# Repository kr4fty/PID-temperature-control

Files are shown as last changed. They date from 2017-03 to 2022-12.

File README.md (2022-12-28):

# PID-temperature-control

Temperature control of an oven/heater made with Arduino Uno (atmega328p microcontroller).
For it, a PID controller is used which will provide a constant temperature at the outlet, according to that established by the user.

This is an implementation of the ovenControl library for Arduino boards.

## Description:
The system maintains a constant temperature at which it is selected. It can vary between 0 and 420ºC.

## Software
These are the libraries required for their operation:

* Lcd: [Adafruit-PCD8544-Nokia-5110-LCD-library](https://github.com/adafruit/Adafruit-PCD8544-Nokia-5110-LCD-library).
* Keyboard: [AnalogKeypad](https://github.com/kr4fty/AnalogKeyPad).
* Menu: [MenuPCD8544](https://github.com/kr4fty/MenuPCD8544).
* K thermocouple: [K-Type_thermocouple-Library](https://github.com/kr4fty/K-Type_thermocouple-Library).
* OvenControl: [ovenControl](https://github.com/kr4fty/ovenControl).

## Hardware:
The system is composed of five main parts

* **The microcontroller**: brain in charge of the administration of resources.
* **Display and keyboard**: is the user interface. It uses a lcd of a Nokia 3310/5510 and a ladder type keyboard.
* **The temperature sensor**: in charge of constantly measuring the temperature of the oven/heater and in this way can make the feedback towards the control for the respective adjustments. For this function a K-type thermocouple  is used.
* **AC control**: in charge of handling AC, in this case I will use 220Vac/50Hz. For this purpose opto-thyristors are used, which act as a solid state relay.
* **Zero crossing detector**: in charge of activating the thyristors from the moment in which the alternating voltage wave is detected crosses by zero.For this function a K-type thermocouple is used.

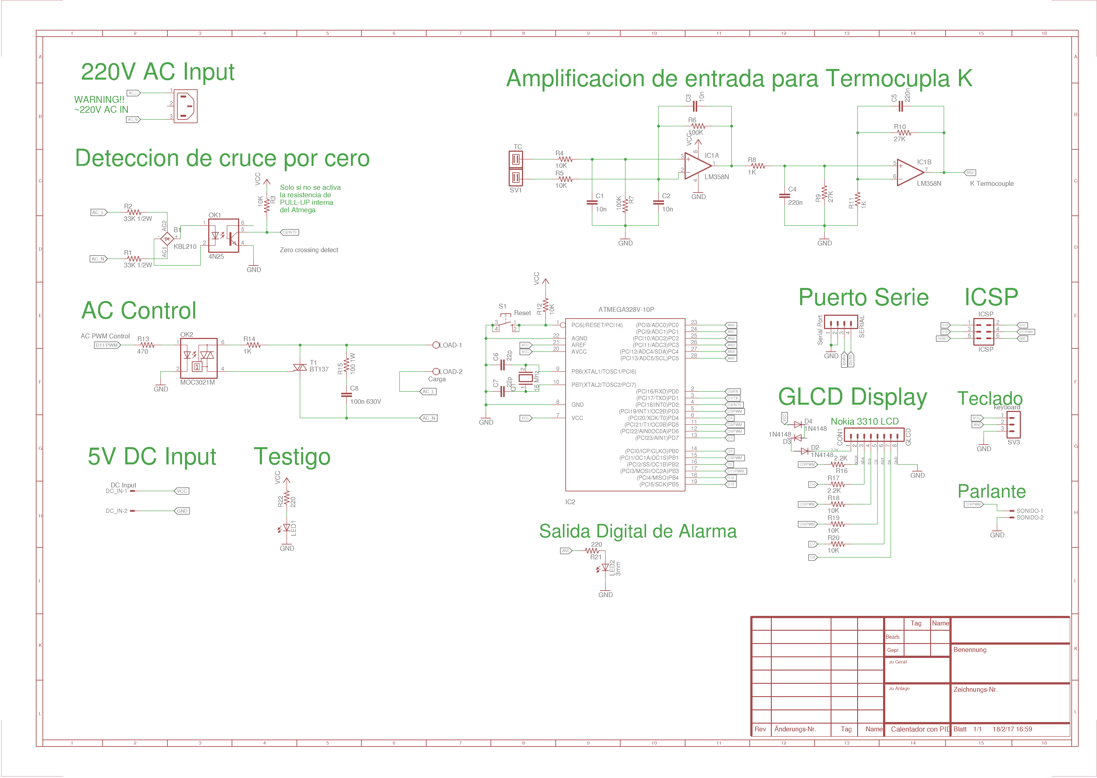
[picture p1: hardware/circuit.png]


## Video
Oven Control (https://www.youtube.com/watch?v=Dz5Lqh4SREI "PID Oven Control")

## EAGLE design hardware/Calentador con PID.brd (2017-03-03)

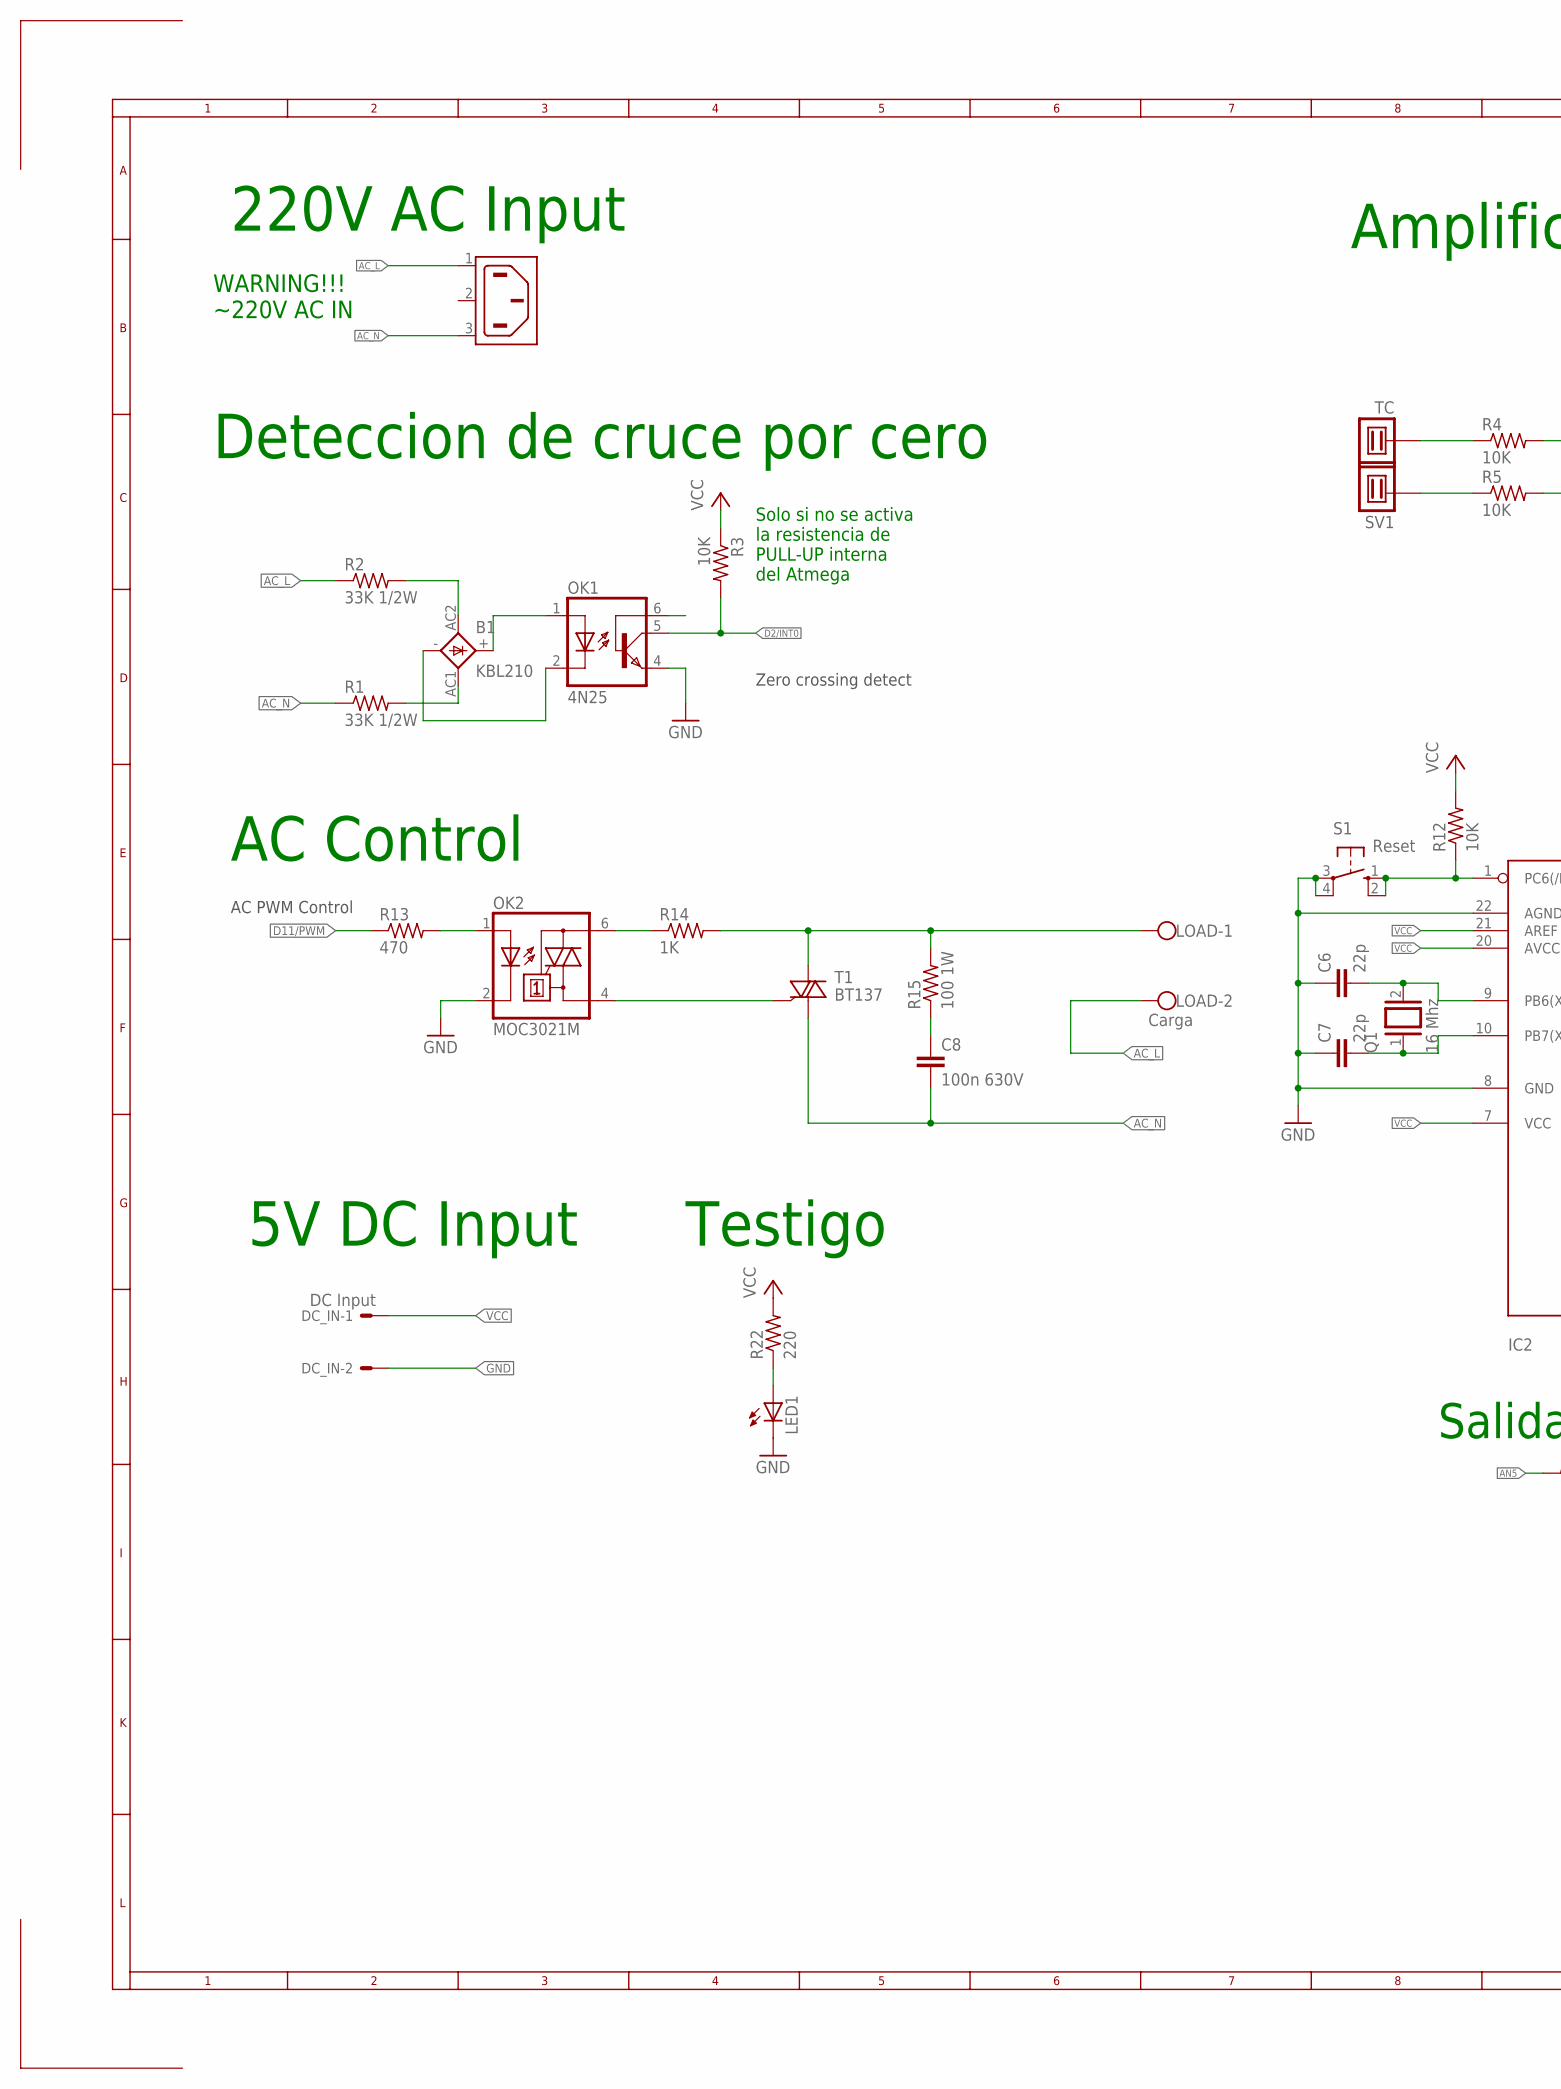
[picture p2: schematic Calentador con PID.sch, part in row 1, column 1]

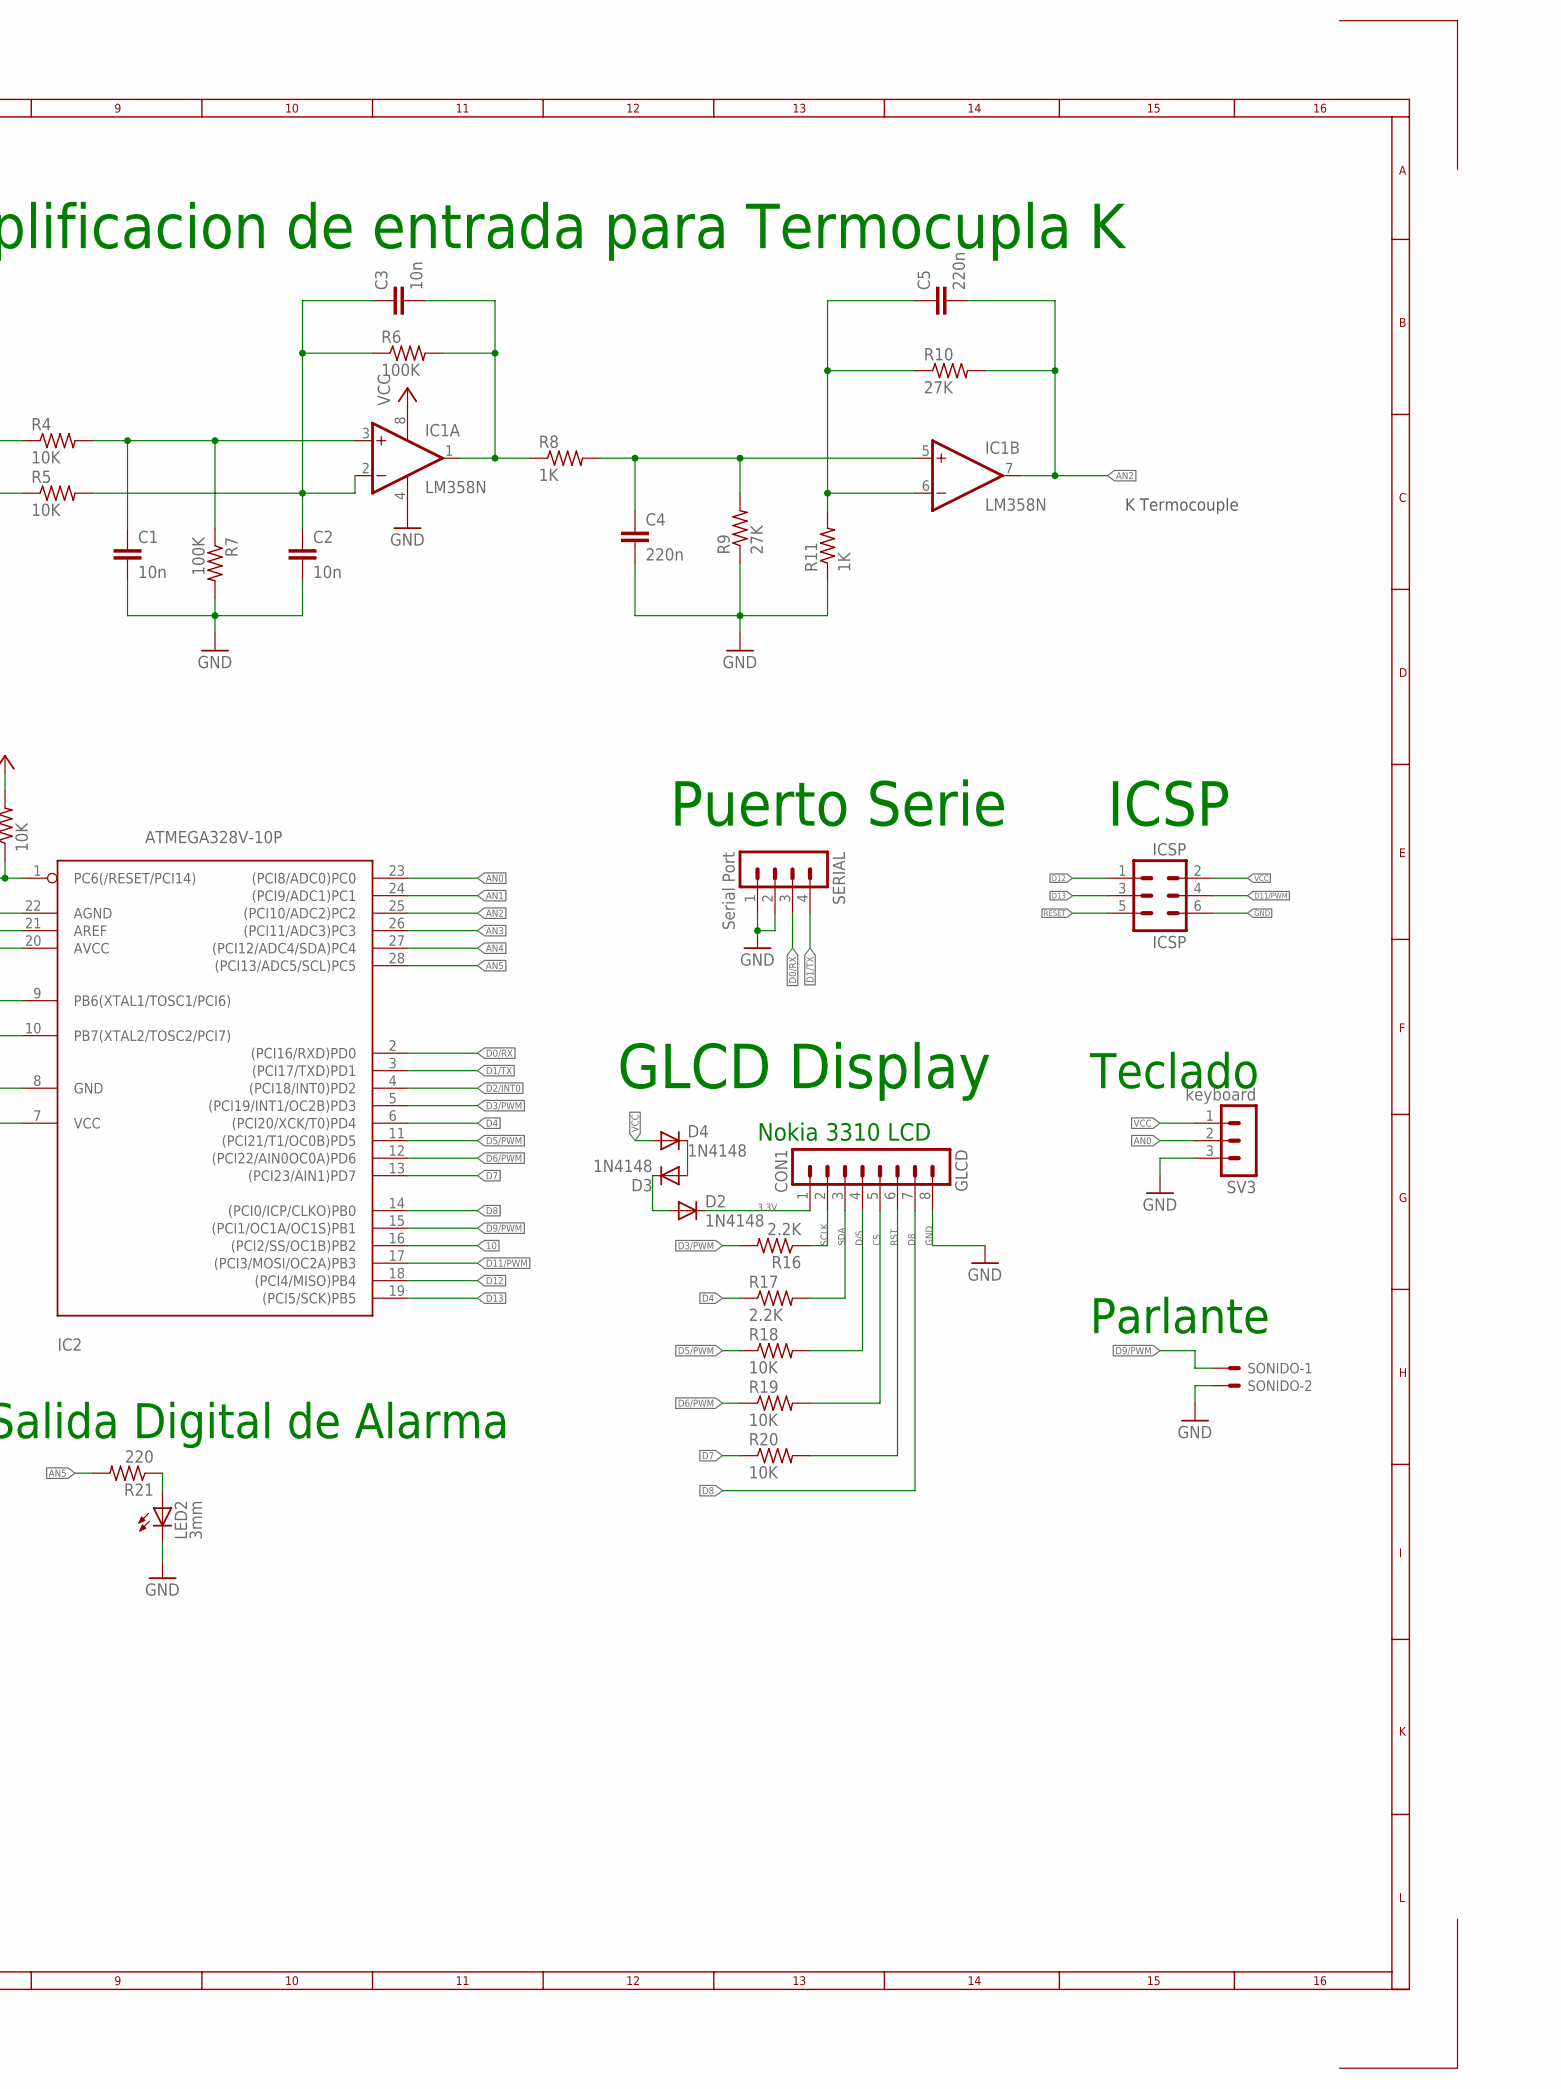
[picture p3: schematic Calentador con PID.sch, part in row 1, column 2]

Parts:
B1: KBL210; KBL
C1, C2, C3: 10n; C050-024X044
C4, C5: 220n; C050-025X075
C6, C7: 22p; C050-025X075
C8: 100n 630V; C102-043X133
D2, D3, D4: 1N4148; DO35-7
DC_IN: DC Input; 22-23-2021
GLCD: CON1; MA08-1
IC1: LM358N; DIL08
IC2: ATMEGA328V-10P; DIL28-3
ICSP: ICSP; MA03-2
LED1: LED3MM
LED2: 3mm; Q62902-B155
LOAD: Carga; W237-102
OK1: 4N25; DIL06
OK2: MOC3021M; DIL06
Q1: 16 Mhz; QS
R1, R2: 33K 1/2W; 0207/2V
R3, R4, R5, R18, R19, R20: 10K; 0207/7
R6: 100K; 0207/2V
R7: 100K; 0207/7
R8, R14: 1K; 0207/2V
R9: 27K; 0207/7
R10: 27K; 0207/2V
R11: 1K; 0207/7
R12: 10K; 0207/15
R13: 470; 0207/10
R15: 100 1W; 0207/2V
R16, R17: 2.2K; 0207/10
R21: 220; 0207/7
R22: 220; 0207/2V
S1: Reset; B3F-10XX
SERIAL: Serial Port; MA04-1
SONIDO: 22-23-2021
SV1: TC; THERMOCOUPLE
SV3: keyboard; MA03-1
T1: BT137; TO220BV
X1: 6ESRM-P

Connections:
3.3V: D2.C, GLCD.1
10: IC2.16 ((PCI2/SS/OC1B)PB2)
AC_L: LOAD.2, R2.1, X1.1 (AC1)
AC_N: C8.2, R1.1, T1.T1 (A1), X1.3 (AC2)
AN0: IC2.23 ((PCI8/ADC0)PC0), SV3.2
AN1: IC2.24 ((PCI9/ADC1)PC1)
AN2: C5.2, IC1.7 (OUT), IC2.25 ((PCI10/ADC2)PC2), R10.2
AN3: IC2.26 ((PCI11/ADC3)PC3)
AN4: IC2.27 ((PCI12/ADC4/SDA)PC4)
AN5: IC2.28 ((PCI13/ADC5/SCL)PC5), R21.2
CS: GLCD.5, R19.2
D0/RX: IC2.2 ((PCI16/RXD)PD0), SERIAL.3
D1/TX: IC2.3 ((PCI17/TXD)PD1), SERIAL.4
D2/INT0: IC2.4 ((PCI18/INT0)PD2), OK1.5 (COL), R3.2
D3/PWM: IC2.5 ((PCI19/INT1/OC2B)PD3), R16.2
D4: IC2.6 ((PCI20/XCK/T0)PD4), R17.1
D5/PWM: IC2.11 ((PCI21/T1/OC0B)PD5), R18.1
D6/PWM: IC2.12 ((PCI22/AIN0OC0A)PD6), R19.1
D7: IC2.13 ((PCI23/AIN1)PD7), R20.1
D8: GLCD.7, IC2.14 ((PCI0/ICP/CLKO)PB0)
D9/PWM: IC2.15 ((PCI1/OC1A/OC1S)PB1), SONIDO.1
D11/PWM: IC2.17 ((PCI3/MOSI/OC2A)PB3), ICSP.4, R13.1
D12: IC2.18 ((PCI4/MISO)PB4), ICSP.1
D13: IC2.19 ((PCI5/SCK)PB5), ICSP.3
D/S: GLCD.4, R18.2
GND: C1.2, C2.2, C4.2, C6.1, C7.1, DC_IN.2, GLCD.8, IC1.4 (V-), IC2.8 (GND), IC2.22 (AGND), ICSP.6, LED1.K (C), LED2.K (C), OK1.4 (EMI), OK2.2 (C), R7.2, R9.1, R11.1, S1.3, S1.4 (P1), SERIAL.1, SERIAL.2, SONIDO.2, SV3.3
unnamed: OK2.1 (A), R13.2
unnamed: OK2.6 (A2), R14.1
unnamed: B1.AC2 (AC1), R2.2
unnamed: B1.AC1 (AC2), R1.2
unnamed: B1.+, OK1.1 (A)
unnamed: B1.-, OK1.2 (C)
unnamed: R4.1, SV1.2
unnamed: C4.1, IC1.5 (+IN), R8.2, R9.2
unnamed: R5.1, SV1.1
unnamed: C2.1, C3.1, IC1.2 (-IN), R5.2, R6.1
unnamed: C3.2, IC1.1 (OUT), R6.2, R8.1
unnamed: C5.1, IC1.6 (-IN), R10.1, R11.2
unnamed: C1.1, IC1.3 (+IN), R4.2, R7.1
unnamed: LOAD.1, R14.2, R15.2, T1.T2 (A2)
unnamed: OK2.4 (A1), T1.G
unnamed: C7.2, IC2.10 (PB7(XTAL2/TOSC2/PCI7)), Q1.1
unnamed: C6.2, IC2.9 (PB6(XTAL1/TOSC1/PCI6)), Q1.2
unnamed: D2.A, D3.C
unnamed: C8.1, R15.1
unnamed: D3.A, D4.C
unnamed: LED2.A, R21.1
unnamed: LED1.A, R22.1
RESET: IC2.1 (PC6(/RESET/PCI14)), ICSP.5, R12.1, S1.1 (S), S1.2 (S1)
RST: GLCD.6, R20.2
SCLK: GLCD.2, R16.1
SDA: GLCD.3, R17.2
VCC: D4.A, DC_IN.1, IC1.8 (V+), IC2.7 (VCC), IC2.20 (AVCC), IC2.21 (AREF), ICSP.2, R3.1, R12.2, R22.2, SV3.1

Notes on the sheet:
Solo si no se activa la resistencia de PULL-UP interna del Atmega
Deteccion de cruce por cero
Amplificacion de entrada para Termocupla K
Puerto Serie
ICSP
AC Control
WARNING!!! ~220V AC IN
220V AC Input
5V DC Input
GLCD Display
Nokia 3310 LCD
Teclado
Parlante
Salida Digital de Alarma
AC PWM Control
Zero crossing detect
K Termocouple
Testigo

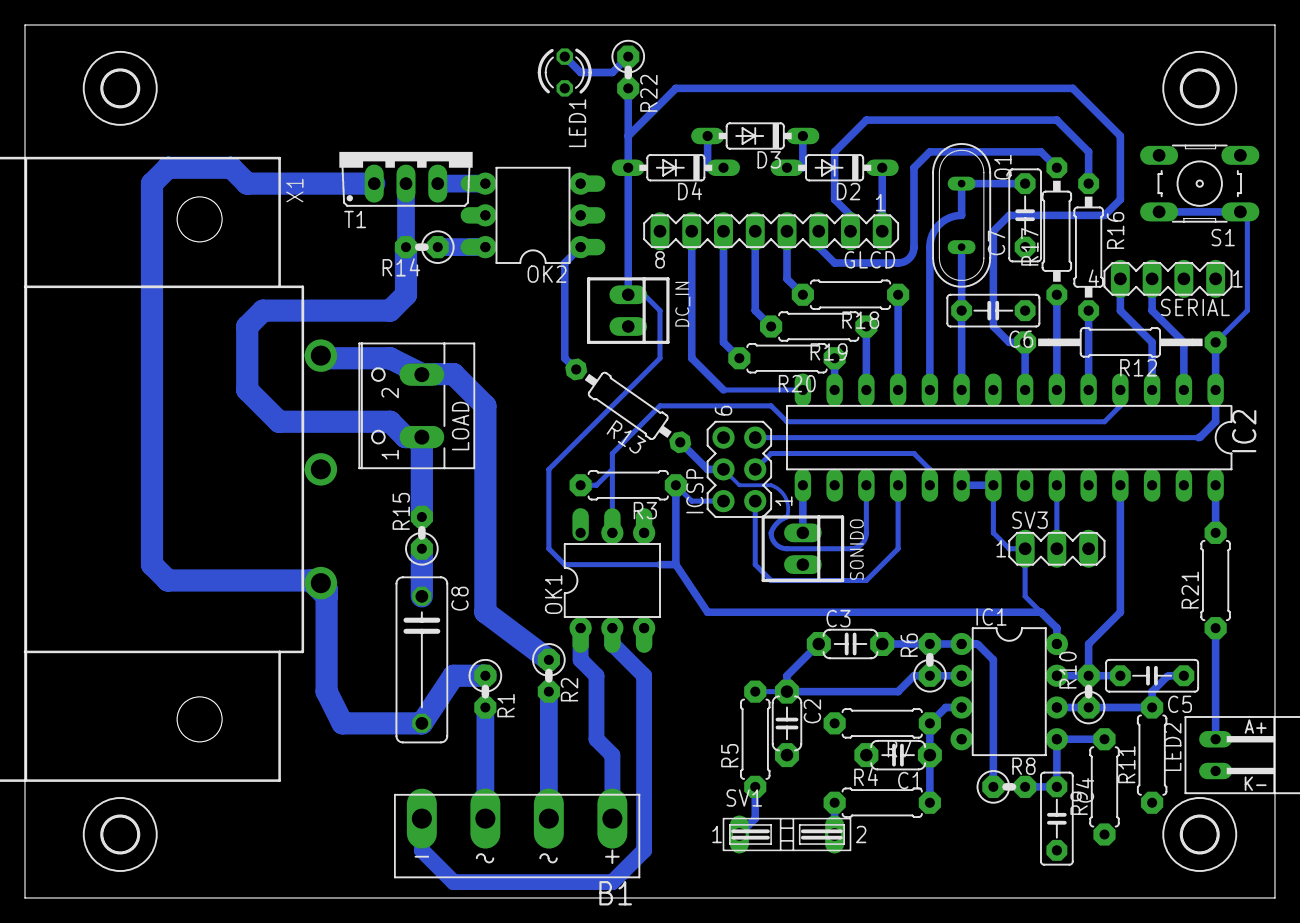
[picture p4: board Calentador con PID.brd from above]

Board: 2 copper layers, 100.0 x 69.8 mm, 56 parts (0 on the bottom side), 49 nets.

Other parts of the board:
U$1, U$2, U$3, U$4: 2,8

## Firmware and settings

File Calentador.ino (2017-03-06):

/*
 *  Nokia 3310/5110, 84x48 pixel monochrome LCD display.
 */
 
#include <MenuPCD8544.h>
#include <AnalogKeyPad.h>
#include <PID_v1.h>
#include <oven.h>
#include <thermo.h>
#include "menu.h"
#include "parameters.h"

extern const menu_t menuRoot;

extern Adafruit_PCD8544 lcd;
extern AnalogKeyPad keypad;
extern MenuPCD8544 menuMain;

double temp= 5, tempAnt;
extern uint16_t tempLimit1;
extern bool showMenuFlag;
extern uint8_t backLightMode;
extern uint32_t autoOffValue;
extern bool alarmEnabled;
extern unsigned long counter;
extern bool isBacklightOn;

extern OvenControl calentador;
extern double setPoint;

extern bool itsRun;
extern bool itsStop;
extern bool waitAHitToUpdate;

void printPrincipal();

unsigned long nextCheck=millis();

void setup()
{
  lcd.begin();
  lcd.setRotation(2);
  lcd.cp437(true);
  pinMode(BACKLIGHTPIN, OUTPUT);
  pinMode(ALARMINDICATORPIN, OUTPUT);
  analogReference(DEFAULT);

  backLightMode = 0;
  digitalWrite(BACKLIGHTPIN, LOW);

  //PID
  setPoint=100;
  calentador.setAccuracy(2);
  calentador.setPWMSkip(0);
  calentador.myPID->SetTunings(KP, KI, KD);
  calentador.moveTo(setPoint);
  //FIN PID

  printPrincipal();

  tone(ALARMSOUNDPIN, 820, 300);
  delay(100);
  tone(ALARMSOUNDPIN, 260, 200);
  delay(100);
  tone(ALARMSOUNDPIN, 440, 300);
  delay(100);
  noTone(ALARMSOUNDPIN);

}

void loop()
{
  menuFunc_t selection;
  int8_t keyCode;

  tempAnt = temp;
  temp = calentador.getActualTemperature();

  //PID
  if (millis() > nextCheck && itsRun && !itsStop)
  {
    nextCheck += 50;
    //Serial.println(temp);

    calentador.run();

    if(!calentador.finished())
    {
      //Serial.println("Controlando temp");
      calentador.moveTo(setPoint);
    }
    else
    {
      //Serial.println("Dentrol del rango");
      calentador.stop();
    }
  }//FIN PID

  if( alarmEnabled )
  {
    if( (tempLimit1-5)<=temp )
    {
      digitalWrite(ALARMINDICATORPIN, HIGH);

      tone(ALARMSOUNDPIN, 2000, 50);
      delay(150);
      tone(ALARMSOUNDPIN, 2000, 100);
    }
    else
    {
      digitalWrite(ALARMINDICATORPIN, LOW);
      noTone(ALARMSOUNDPIN);
    }
  }

  if( (temp != tempAnt) && (!showMenuFlag) && (!waitAHitToUpdate))
  {
    printTemp(temp);
    lcd.display();
  }

  if( (!isBacklightOn) && (backLightMode==2) )  // Si esta apagado, modo auto y mostrando temps
  {
    if( keypad.keyUpEvent() != AnalogKeyPad::NO_KEY )
    {
      counter = millis();
      digitalWrite(BACKLIGHTPIN, HIGH);
      isBacklightOn = true;
    }
  }
  else
  {
    if( !waitAHitToUpdate )
    {
      if( !showMenuFlag )
      {
        if( keypad.keyUpEvent() != AnalogKeyPad::NO_KEY )
        {
          if(backLightMode==2)
            counter = millis();
          if( (keypad.getCurrentKey() == AnalogKeyPad::UP ) && !itsStop )
          {
            runPauseProcess();
            printPrincipal();
          }
          if( keypad.getCurrentKey() == AnalogKeyPad::SELECT )
          {
            tone(ALARMSOUNDPIN, 200, 200);
            delay(100);
            tone(ALARMSOUNDPIN, 440, 300);
            delay(100);
            noTone(ALARMSOUNDPIN);

            lcd.clearDisplay();

            showMenuFlag = true;
            menuMain.begin(&lcd);
          }
        }
      }
      else
      {
        selection = taskMenu();             // run the menu task
        if ( selection != NULL )            // menu item selected?
        {
          showMenuFlag = false;
          (*selection)();                   // then execute it

          if( !waitAHitToUpdate )
          {
            printPrincipal();
          }

          tone(ALARMSOUNDPIN, 480, 300);
          delay(100);
          tone(ALARMSOUNDPIN, 200, 200);
          delay(100);
          noTone(ALARMSOUNDPIN);
        }
      }
    }
    else
      if( keypad.keyUpEvent() != AnalogKeyPad::NO_KEY )
      {
        waitAHitToUpdate = false;
        printPrincipal();
      }
  }

  if( (backLightMode==2) &&  ((millis()-counter) > autoOffValue) )
  {
    digitalWrite(BACKLIGHTPIN, LOW);
    isBacklightOn = false;
  }
}


// handle the menu
menuFunc_t taskMenu()
{
	menuFunc_t doit = NULL;
	int8_t keyCode;

  if ( (keyCode = keypad.keyUpEvent()) != AnalogKeyPad::NO_KEY )       // was key pressed?
  {
    if( (!isBacklightOn) && (backLightMode==2) )
    {
      digitalWrite(BACKLIGHTPIN, HIGH);
      isBacklightOn = true;
    }
    counter = millis();

    tone(ALARMSOUNDPIN, 440, 50);
    delay(50);
    noTone(ALARMSOUNDPIN);

    // valid input keycodes: U,D,L,R,S - Up, Down, Left, Right, Select
    // returns true if menu item was selected and *doit holds the associated function pointer
    int8_t selected = menuMain.navigate(keyCode, &doit);

    if (selected)               		        // user selected the menu item
    {
      if (doit == MenuPCD8544::canceled)      // check that the menu was not canceled
      {   doit = NULL;

        printPrincipal();

        showMenuFlag = false;
      }
    }
  } // end process keycode
  return doit;
}

void printPrincipal()
{
    lcd.clearDisplay();
    lcd.setTextSize(1);
    lcd.setTextColor(BLACK, WHITE);

    if( !itsStop )
    {
      lcd.print("Setpoint= ");
      lcd.print((uint16_t)setPoint);

      if( !itsRun )
        setStatus("   Paused");
      else
        setStatus("  Running...");
    }

    else
    {
      lcd.print("Temperatura");
      setStatus("  OK -> Menu");
    }
    lcd.setTextSize(2);
    lcd.setCursor(53, 14);
    lcd.print((char)248);
    lcd.print("C");

    temp --;
}

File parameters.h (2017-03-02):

#ifndef _PARAMETERS_H
#define _PARAMETERS_H

#define DISPLAYSCKPIN      3
#define DISPLAYDINPIN      4
#define DISPLAYDCPIN       5
#define DISPLAYCSPIN       6
#define DISPLAYRSTPIN      7
#define BACKLIGHTPIN       8

#define ANALOGKEYPADPIN    A0
#define THERMOCOUPLEPIN    A2
#define ALARMINDICATORPIN  A5
#define ZEROCROSSPIN       2
#define ALARMSOUNDPIN      9
#define PWMOUTPUTPIN       11

#define KP                50
#define KI                0.5
#define KD                0.01

#endif

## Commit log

2017-03-03 second commit
    [Calentador con PID.brd, Calentador con PID.sch]
2017-03-05 Bug fixes. Block produced by acercade() function when process control was running
    [Calentador.ino, menu.cpp]
2017-03-05 bugfix: avoid blocking the PID controller program
    [Calentador.ino, menu.cpp]
2017-03-06 probando actualizar repo utilizando git+ de Atom/PlatmormIO
2017-06-01 rename folder
    [Calentador con PID.brd, Calentador con PID.sch]
